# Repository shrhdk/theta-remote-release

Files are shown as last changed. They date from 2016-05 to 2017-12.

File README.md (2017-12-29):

# THETA簡単リモコン

5秒でRICOH THETA Sと接続できる簡単リモコンの設計を公開しています。

(https://www.youtube.com/watch?v=02DGiVLA_kg)

## 機能

- THETA Sのシャッターを切る
- THETA Sの動画撮影開始/停止
- Webブラウザで接続するTHETA Sを設定
- Webブラウザでファームウェアをアップデート
- USB充電

詳細は[操作説明](doc/instruction-manual.md)を御覧ください。

## プロジェクト構成

```
theta-remote-release/
  |-- hardware/       回路図・基板図 (KiCad)
  |-- src/            ファームウェア (Arduino)
  |-- platformio.ini  PlatformIOのプロジェクトファイル
```

## ハードウェア

回路図、プリント基板は[KiCad](http://kicad-pcb.org/)で設計しました。

`hardware/theta-remote-release.pro`をKiCadで開いてください。

- [回路図](hardware/theta-remote-release.sch.svg)
- [部品リスト](hardware/parts.md)

## ファームウェア

このプロジェクトはArduino ([PlatformIO](http://platformio.org/))を利用しています。

次の手順でファームをビルドしてリモコンに書き込めます。

1. PCのシリアルポートとリモコンのDEBUGコネクタを接続
2. リモコンの電源ON
3. 次のコマンドを実行

```
# もしPlatformIOがなければインストールする (Pythonが必要です)
$ pip install -U pip setuptools     
$ pip install -U platformio

# このリポジトリをCloneする
$ git clone https://github.com/shrhdk/theta-remote-release.git

# ビルドしてリモコン(ESP8266)にアップロードする
$ cd theta-remote-release
$ pio run --target upload
```

## 組み立て例

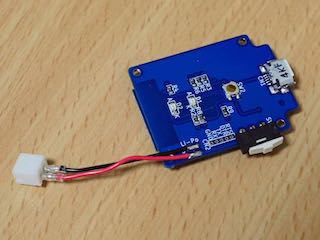
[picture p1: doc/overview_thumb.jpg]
組み立て済みの写真


- [基板表面](doc/front.jpg)
- [基板裏面](doc/back.jpg)

## License

- This project is released under the MIT license.

## 謝辞

このプロジェクトは以下のソフトウェア・資料を利用しています。

- [aJson](https://github.com/interactive-matter/aJson) Copyright (c) 2010, Interactive Matter, Marcus Nowotny
- [ここであえてのESP-WROOM-02用変換基板 - ゆるりとものづくり](http://monomake.hatenablog.com/entry/2015/08/12/esp-wroom-02/)

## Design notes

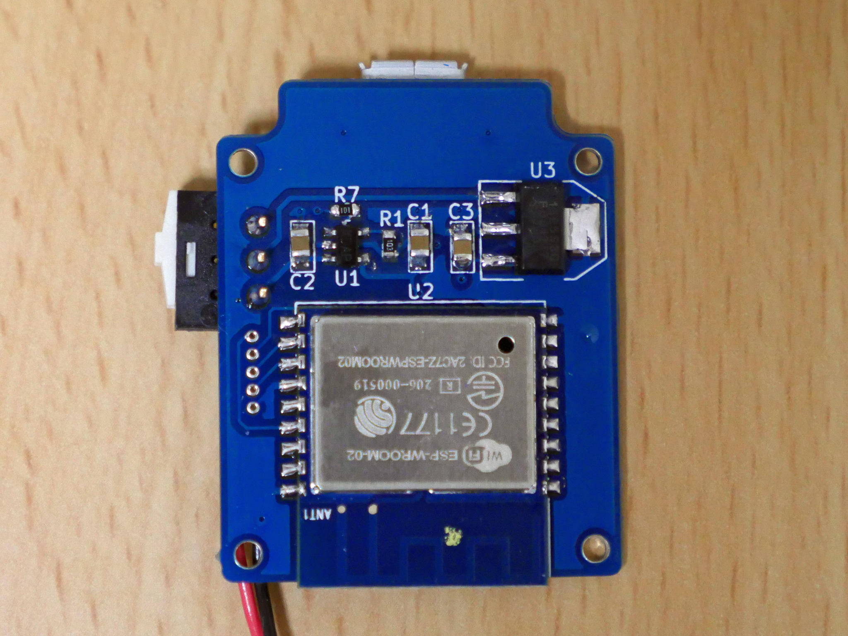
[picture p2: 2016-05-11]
doc/back.jpg

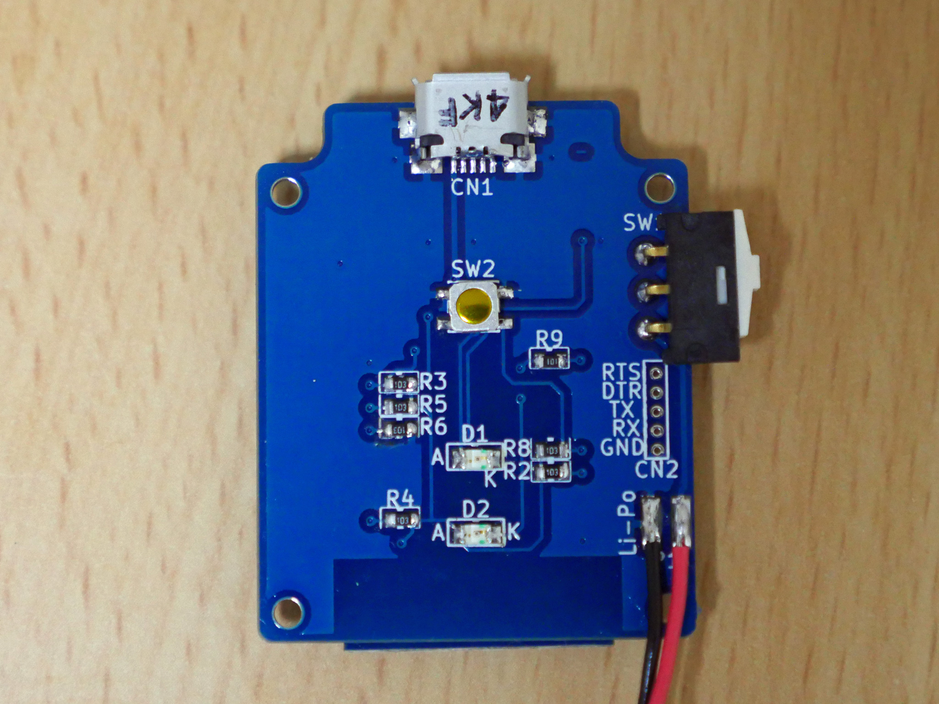
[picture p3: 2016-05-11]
doc/front.jpg

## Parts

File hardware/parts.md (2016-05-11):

# 部品リスト

| Ref. | Name | Model/Value | Package | URL |
|:----:|---|---|---|---|
| C1 | Capacitor | 4.7uF | 2012 | http://akizukidenshi.com/catalog/g/gP-07548/ |
| C2 | Capacitor | 4.7uF | 2012 | http://akizukidenshi.com/catalog/g/gP-07548/ |
| C3 | Capacitor | 4.7uF | 2012 | http://akizukidenshi.com/catalog/g/gP-07548/ |
| CN1  | Micro USB Conn. | ZX62R-B-5P | | http://akizukidenshi.com/catalog/g/gC-05254/ |
| CN2  | DEBUG | Pin Socket | 5pin, 1.27mm | http://akizukidenshi.com/catalog/g/gC-08695/ |
| D1 | Orange LED | OSO50805C1C | 2012 | http://akizukidenshi.com/catalog/g/gI-06422/ |
| D2 | Green LED | OSG80805C1C | 2012 | http://akizukidenshi.com/catalog/g/gI-06421/ |
| R1 | Register | 10k | 1608 | http://akizukidenshi.com/catalog/g/gR-06103/ |
| R2 | Register | 10k | 1608 | http://akizukidenshi.com/catalog/g/gR-06103/ |
| R3 | Register | 10k | 1608 | http://akizukidenshi.com/catalog/g/gR-06103/ |
| R4 | Register | 10k | 1608 | http://akizukidenshi.com/catalog/g/gR-06103/ |
| R5 | Register | 10k | 1608 | http://akizukidenshi.com/catalog/g/gR-06103/ |
| R6 | Register | 10k | 1608 | http://akizukidenshi.com/catalog/g/gR-06103/ |
| R7 | Register | 100 | 1608 | http://akizukidenshi.com/catalog/g/gR-06101/ |
| R8 | Register | 10k | 1608 | http://akizukidenshi.com/catalog/g/gR-06103/ |
| R9 | Register | 100 | 1608 | http://akizukidenshi.com/catalog/g/gR-06101/ |
| SW1  | Slide Switch | ESP2020 | 3pin, 2.54mm | http://eleshop.jp/shop/g/gC5U122/ |
| SW2  | Push Switch | TVAF17-WEC-R | | http://akizukidenshi.com/catalog/g/gP-08081/ |
| U1 | Li-Po Charger | MCP73831T-2ACI | SOT-23-5 | http://www.aitendo.com/product/6258 |
| U2 | Processor | ESP-WROOM-02 | | http://akizukidenshi.com/catalog/g/gM-09607/ |
| U3 | LDO Regulator | MCP1825S-3002E/DB | SOT-223 | http://jp.rs-online.com/web/p/low-dropout-voltage-regulators/6695089/ |
| E1 | Li-Po Battery | 110mAh | | https://www.switch-science.com/catalog/157/ |

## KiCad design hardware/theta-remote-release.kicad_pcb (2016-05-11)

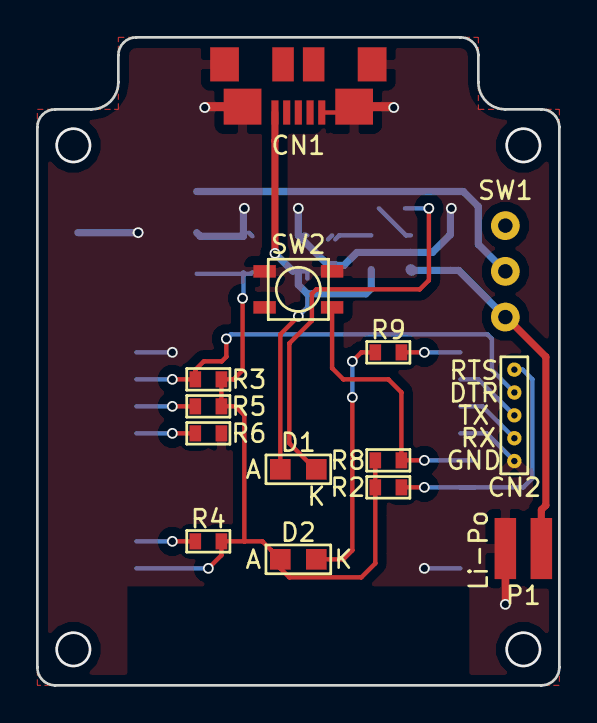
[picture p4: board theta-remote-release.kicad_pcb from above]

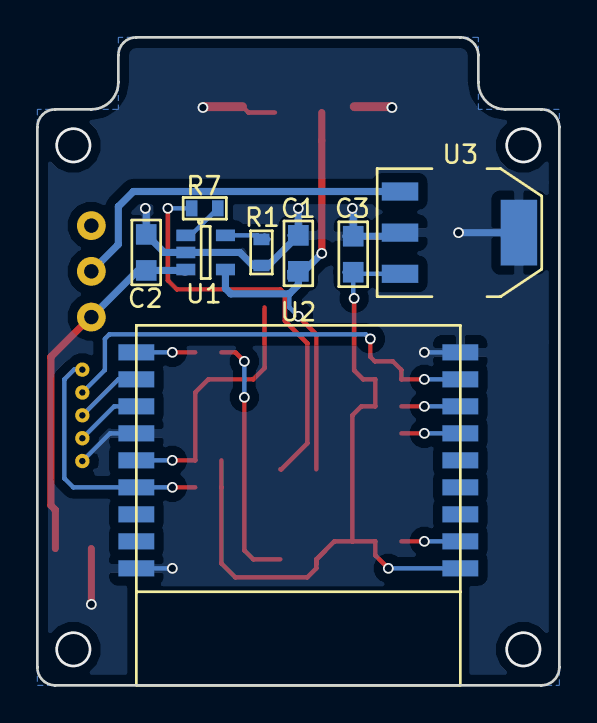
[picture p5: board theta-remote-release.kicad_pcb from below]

Board: 2 copper layers, 29.0 x 36.0 mm, 22 parts (8 on the bottom side), 18 nets.

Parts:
C1, C2, C3: 4.7uF; SMD2012
CN1: ZX62R-B-5P
CN2: DEBUG; Debug
D1: CHG; SMD2012_LED
D2: STAT; SMD2012_LED
P1: Li-Po 3.7V; Li-Po
R1, R2, R3, R4, R5, R6, R8: 10k; SMD1608
R7, R9: 100; SMD1608
SW1: POWER; ESP2020
SW2: SHUTTER; TVAF17-WEC-R
U1: MCP73831; SOT-23-5
U2: ESP-WROOM-02; esp-wroom-02
U3: MCP1825S-3002E/DB; SOT-223

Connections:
+3V: C3.1, D2.2, R2.1, R3.1, R4.1, R5.1, R8.1, U2.1, U3.3
+5V: C1.1, CN1.1, D1.2, U1.4
/CHG: R7.2, U1.1
/IO4: R9.2, U2.10
/IO5: R8.2, SW2.1, U2.14
GND: C1.2, C2.2, C3.2, CN1.5, CN1.6, CN2.5, P1.2, R1.1, R6.1, SW2.3, SW2.4, U1.2, U2.9, U2.13, U2.18, U3.2, U3.4
unnamed: C2.1, P1.1, SW1.3, U1.3
unnamed: CN2.1, R2.2, U2.15
unnamed: CN2.2, R3.2, U2.8
unnamed: CN2.3, U2.11
unnamed: CN2.4, U2.12
unnamed: D1.1, R7.1
unnamed: D2.1, R9.1
unnamed: R1.2, U1.5
unnamed: R4.2, U2.2
unnamed: R5.2, U2.7
unnamed: R6.2, U2.6
unnamed: SW1.2, U3.1

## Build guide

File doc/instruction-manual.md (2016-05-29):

# THETA簡単リモコンの使い方

## 機能

- THETA Sのシャッターを切る
- THETA Sの動画撮影開始/停止
- Webブラウザで接続するTHETA Sを設定
- Webブラウザでファームウェアをアップデート
- USB充電

## LEDの意味

充電LED: 橙, メインLED: 緑

- 充電LED点灯: 充電中
- メインLED点滅: THETA Sに接続中
- メインLED点灯: THETA Sに接続完了/設定モード起動中
- メインLED消灯: 撮影中

## 使い方

※はじめに、THETA Sへの接続設定を行う必要があります。

THETA SとTHETAリモコンの電源を入れると自動的に接続が始まります。
THETAリモコンのメインLEDが点灯すれば接続完了です。
接続には5秒程度かかります。

ボタンを押すと静止画モードであれば、シャッターを切ります。
動画モードであれば、撮影を開始/停止します。

充電はMicro USB端子にUSB電源を接続してください。

## 接続設定

1. ボタンを押しながらリモコンの電源を入れる。
2. LEDが点滅ではなく点灯していれば、設定モードで起動している。
3. PCやスマートフォンのWi-FiでSSID:`theta-remote-release`に接続する。(パスフレーズは不要)
4. `theta-remote-release`に接続した端末のWebブラウザで`http://192.168.1.1/`にアクセスする。
5. フォームが表示されるので、THETA SのSSIDとパスワードを入力する。([参考](https://theta360.com/ja/support/manual/s/content/prepare/prepare_06.html))
6. フォームを送信して、成功ページが表示されたら、リモコンの電源を入れなおす。

## ファームウェアアップデート

最新のファームウェア (`firmware.bin`)は[リリース一覧](https://github.com/shrhdk/theta-remote-release/releases)から入手できます。

1. ボタンを押しながらリモコンの電源を入れる。
2. LEDが点滅ではなく点灯していれば、設定モードが起動している。
3. PCやスマートフォンのWi-FiでSSID:`theta-remote-release`に接続する。
4. `theta-remote-release`に接続した端末のWebブラウザで`http://192.168.1.1/update`にアクセスする。
5. フォームが表示されるので、`firmware.bin`を選択してフォームを送信する。
6. `OK`と表示されれば完了

※ファームウェアアップデート後は改めて接続設定をしてください。

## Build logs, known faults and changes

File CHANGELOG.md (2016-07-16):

# ChangeLog

## 1.1.1

- ハードウェア
  - 変更なし
- ソフトウェア
  - `ESP8266HTTPClient.cpp`を削除

## 1.1.0

- ハードウェア
  - 変更なし
- ソフトウェア
  - 動画撮影対応
  - 連続撮影対応
  - 接続時間短縮 (約1秒短縮)

## 1.0.0

`0.0.1`から全面改訂

## 0.0.1

[3秒でTHETA Sとつながるリモートシャッターを作る](http://shrhdk.hatenablog.com/entry/theta-remote-release)で紹介したバージョン

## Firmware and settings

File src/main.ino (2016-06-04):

/*
 * Copyright (c) 2016 Hideki Shiro
 */

#include "settings_server.h"
#include "button.h"
#include "led.h"
#include "settings.h"
#include "theta_s.h"

Button button(5);
LED led(4);

// THETA

void connect(const char *ssid, const char *password) {
    ThetaS.connect(ssid, password);
    while(ThetaS.status() != WL_CONNECTED) {
        delay(300);
        led.toggle();
        Serial.print(".");
    }
}

// Entry Point

void setup() {
    Serial.begin(115200);
    Serial.println("theta-remote-release");

    if(button.isPressed()) {
        led.on();
        SettingsServer.start();
        for(;;) {
            SettingsServer.handle();
        }
    }

    Settings.load();
}

void loop() {
    if(ThetaS.status() != WL_CONNECTED) {
        led.off();
        connect(Settings.ssid, Settings.password);
        ThetaS.startSession();
        led.on();
    } else if(button.isPressed()) {
        led.off();
        ThetaS.shoot();
        led.on();
    }

    ThetaS.handle();
}

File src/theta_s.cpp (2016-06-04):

/*
 * Copyright (c) 2016 Hideki Shiro
 */

#include "theta_s.h"
#include "osc_command.h"
#include <ESP8266HTTPClient.h>
#include <ESP8266WiFi.h>
#include <Ticker.h>
#include <arduino.h>
#include <stdint.h>
#include <strings.h>

// file scope

Ticker ticker;

const int UPDATE_SESSION_PERIOD = 160;

bool needToUpdateSession = false;

void updateSessionFlag() { needToUpdateSession = true; }

void enableUpdateSessionEvent() {
  needToUpdateSession = false;
  ticker.attach(UPDATE_SESSION_PERIOD, updateSessionFlag);
}

void disableUpdateSessionEvent() { ticker.detach(); }

// public

void ThetaSClass::connect(const char *ssid, const char *password) {
  WiFi.begin(ssid, password);
}

wl_status_t ThetaSClass::status() { return WiFi.status(); }

int ThetaSClass::startSession() {
  Serial.println("ThetaS::startSession");

  disableUpdateSessionEvent();

  OSCCommand cmd("camera.startSession");

  cmd.execute();

  if (cmd.statusCode != 200) {
    return 1;
  }

  strcpy(sessionID, cmd.getResultString("sessionId"));

  enableUpdateSessionEvent();

  return 0;
}

int ThetaSClass::updateSession() {
  Serial.println("ThetaS::updateSession");

  disableUpdateSessionEvent();

  // Construct Request
  OSCCommand cmd("camera.updateSession");
  cmd.addParameter("sessionId", sessionID);

  cmd.execute();

  if (cmd.statusCode != 200) {
    return 1;
  }

  strcpy(sessionID, cmd.getResultString("sessionId"));

  enableUpdateSessionEvent();

  return 0;
}

int ThetaSClass::takePicture() {
  return executeSimpleCommand("camera.takePicture");
}

int ThetaSClass::startCapture() {
  return executeSimpleCommand("camera._startCapture");
}

int ThetaSClass::stopCapture() {
  return executeSimpleCommand("camera._stopCapture");
}

int ThetaSClass::shoot() {
  int result = takePicture();

  if (result != 2) {
    return result;
  }

  result = startCapture();

  if (result != 2) {
    return result;
  }

  return stopCapture();
}

int ThetaSClass::handle() {
  if (needToUpdateSession) {
    return ThetaS.updateSession();
  }

  return 0;
}

// private

int ThetaSClass::executeSimpleCommand(const char *name) {
  Serial.println(name);

  OSCCommand cmd(name);
  cmd.addParameter("sessionId", sessionID);

  cmd.execute();

  if (strcmp(cmd.code, "disabledCommand") == 0) {
    return 2;
  }

  if (cmd.statusCode != 200) {
    return 1;
  }

  return 0;
}

ThetaSClass ThetaS;

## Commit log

2015-12-16 Initial Commit
    Add hardware and code
    [theta-remote-release.kicad_pcb, theta-remote-release.sch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]
2016-05-11 add reference
    [theta-remote-release.kicad_pcb]
2016-05-11 add 1.0.0
    [theta-remote-release.kicad_pcb, theta-remote-release.sch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]
2016-05-29 remove ArduinoJson
2016-07-16 board = esp_wroom_02
2016-07-16 remove ESP8266HTTPClient.cpp. (https://github.com/esp8266/Arduino/pull/2060)
2016-07-16 remove redundant header including. (https://github.com/esp8266/Arduino/pull/2094)
2017-12-29 fix URL for "ここであえてのESP-WROOM-02用変換基板"
